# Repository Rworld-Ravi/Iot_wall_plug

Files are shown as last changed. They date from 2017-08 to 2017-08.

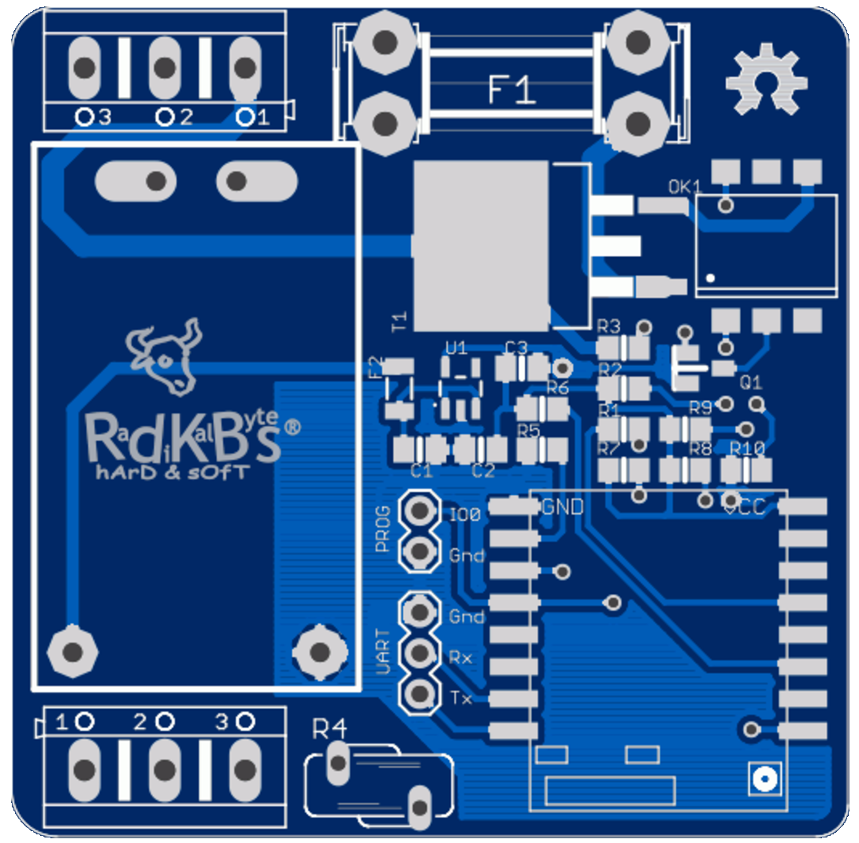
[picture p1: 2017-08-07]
Art/top.png

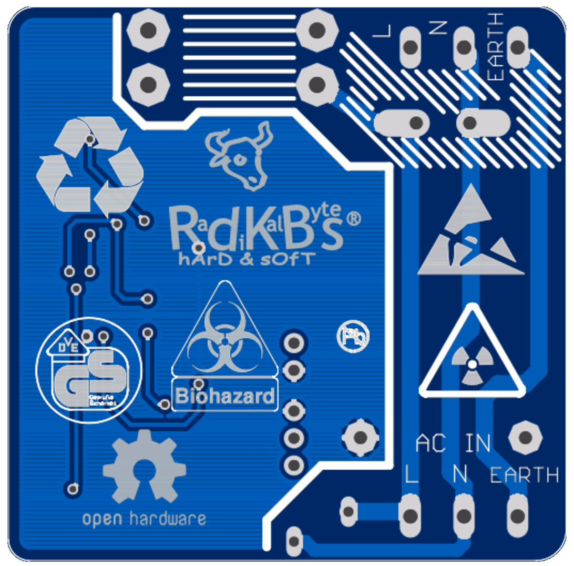
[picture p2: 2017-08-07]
Art/bottom.png

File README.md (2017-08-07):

# IoT wall plug standard

This is a circuit to control any 220v AC device under 4A plugged it.  

## Getting Started with another firmware  

To program the ESP8266 ESP-07 you need an USB <--> serial converter at 3,3v (5v will damage the ESP-07 IOs).  
You can use Arduino IDE to update own sketches.  
Or you can install another firmware in ESP-07 as Lua, uPython, ESPeasy...  
To install another firmware:
* Disconnect device from power  
* Shortcut jumper (IO0 and GND)  
* Connect your favorite USB-serial converter at RX,TX,GND pins  
* Apply power to device (Be careful with 220v AC)
* Upload your firmware with esptool.exe (windows) or another tool for OSX, Linux...  
* Disconnect the jumper (IO0 and GND)
* And restart device

## Built With

[EagleCAD](https://www.autodesk.com/products/eagle/overview)

## Authors

* **RadikalBytes** - *Alfredo Prado* - [@radikalbytes](https://twitter.com/radikalbytes)

## License
<br />This work is licensed under a <a rel="license" href="http://creativecommons.org/licenses/by-sa/3.0/">Creative Commons Attribution-ShareAlike 3.0 Unported License</a>.

## Acknowledgments

* To my brain for support me every hour ;)

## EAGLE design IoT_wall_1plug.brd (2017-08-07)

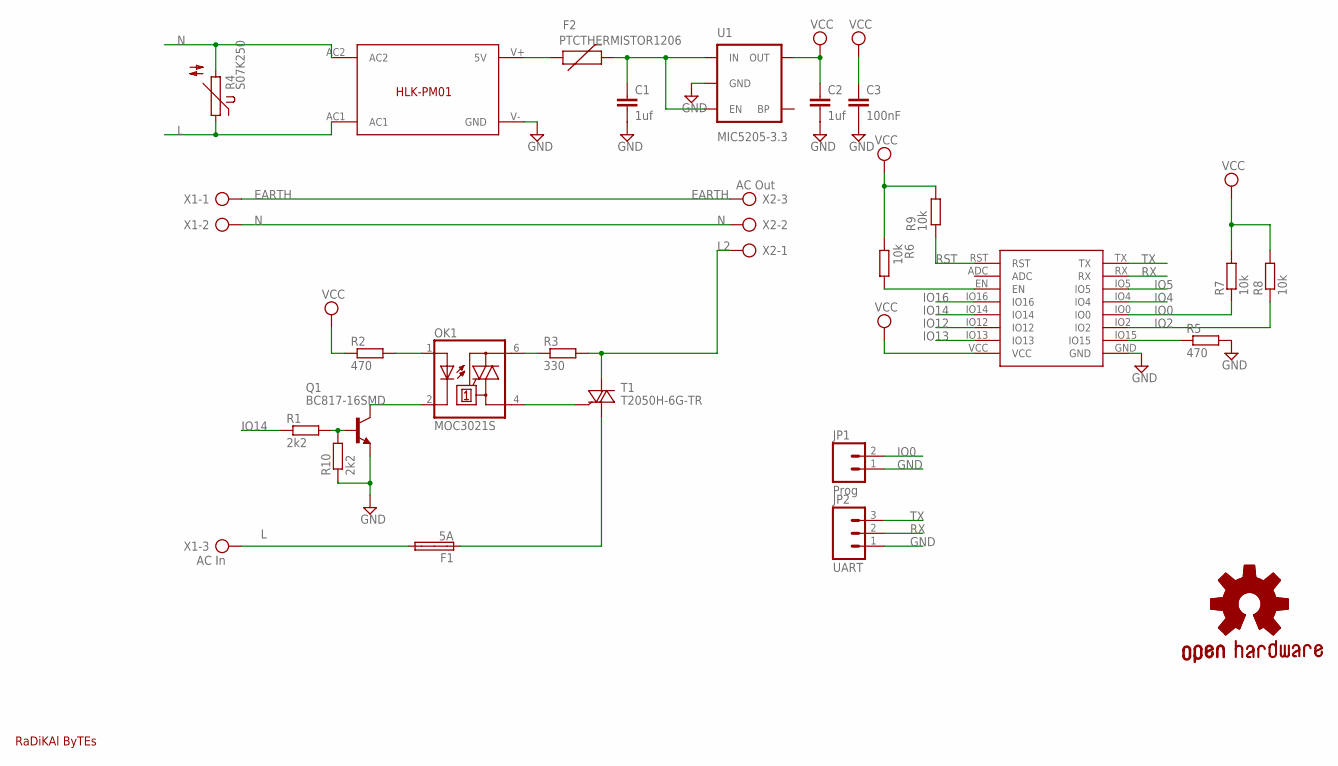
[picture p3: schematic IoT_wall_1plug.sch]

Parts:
C1, C2: 1uf; RCL_C0805K
C3: 100nF; RCL_C0805K
F1: 5A; SHK20Q
F2: PTCTHERMISTOR1206; SPARKFUN-POWERIC_PTC-1206
GOLD_ORB_SM1: OSHWLOGO_GOLD_ORB_MED; OSHW1
JP1: Prog; SPARKFUN-CONNECTORS_1X02
JP2: UART; SPARKFUN-CONNECTORS_1X03
OK1: MOC3021S; DIL6-SMD
Q1: BC817-16SMD; SOT23-BEC
R1, R10: 2k2; R0805
R2, R5: 470; R0805
R3: 330; R0805
R4: S07K250
R6, R7, R8, R9: 10k; R0805
T1: T2050H-6G-TR; D2PAK-3
U1: MIC5205-3.3; SPARKFUN-POWERIC_SOT23-5
U$1: HLK-PM01
U$2: DAVLIB_ESP8266
U$4: MI_LOGO1.5MM; MI_LOGO_PEQUEÑO
X1: AC In; AK500/3
X2: AC Out; AK500/3

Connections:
EARTH: X1.1, X2.3
GND: C1.2, C2.2, C3.2, JP1.1, JP2.1, Q1.E, R5.2, R10.1, U1.2 (GND), U$1.V- (GND), U$2.GND
IO0: JP1.2, R7.1, U$2.IO0
IO2: R8.1, U$2.IO2
IO4: U$2.IO4
IO5: U$2.IO5
IO12: U$2.IO12
IO13: U$2.IO13
IO14: R1.1, U$2.IO14
IO16: U$2.IO16
L: F1.2A, R4.1, U$1.AC1, X1.3
L2: R3.2, T1.4 (A2), X2.1
N: R4.2, U$1.AC2, X1.2, X2.2
unnamed: Q1.B, R1.2, R10.2
unnamed: OK1.1 (A), R2.2
unnamed: OK1.6 (A2), R3.1
unnamed: OK1.2 (C), Q1.C
unnamed: F1.1A, T1.1 (A1)
unnamed: F2.1, U$1.V+ (5V)
unnamed: OK1.4 (A1), T1.3 (G)
unnamed: C1.1, F2.2, U1.1 (IN), U1.3 (EN)
unnamed: R6.2, U$2.EN
unnamed: R5.1, U$2.IO15
RST: R9.1, U$2.RST
RX: JP2.2, U$2.RX
TX: JP2.3, U$2.TX
VCC: C2.1, C3.1, R2.1, R6.1, R7.2, R8.2, R9.2, U1.5 (OUT), U$2.VCC

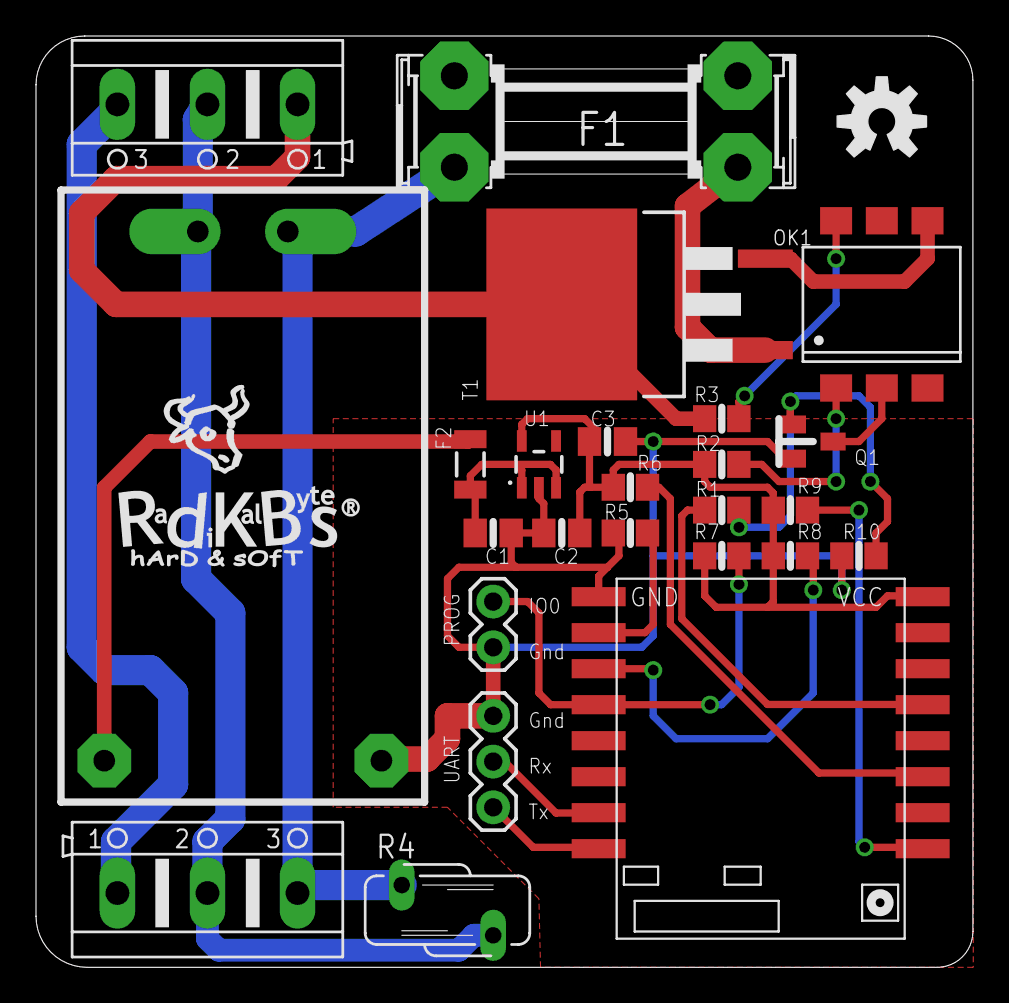
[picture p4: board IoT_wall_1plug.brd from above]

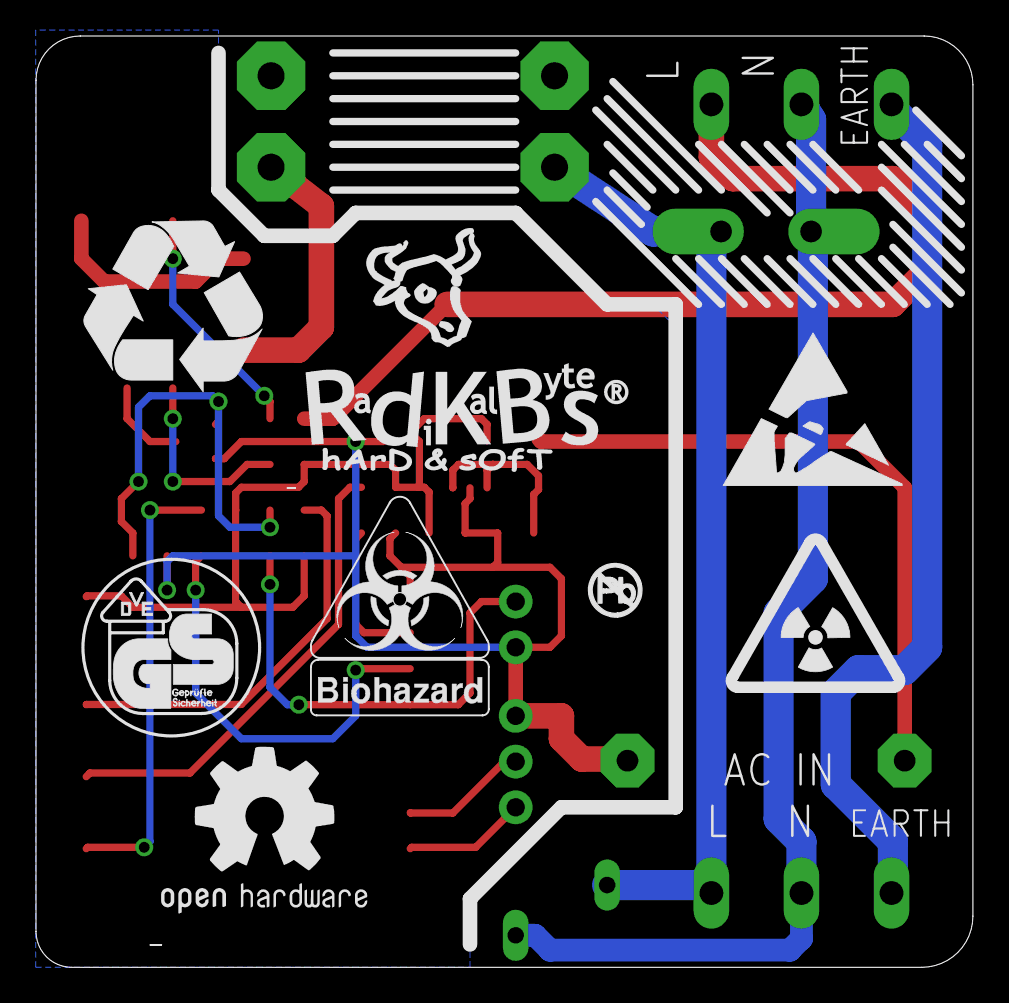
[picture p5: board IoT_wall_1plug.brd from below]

Board: 2 copper layers, 52.0 x 51.7 mm, 35 parts (8 on the bottom side), 22 nets.

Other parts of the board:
U$3: OSHW-LOGO-M
U$5: VDE-GS_10.00
U$6: RECYCLING_10.00
U$7: RADIOACTIVE_10.00
U$8: ESD_10.00
U$9: BIOHAZARD_10.00
U$10: NO_PB_LOGO_0.120
U$12: MI_LOGO_2MM

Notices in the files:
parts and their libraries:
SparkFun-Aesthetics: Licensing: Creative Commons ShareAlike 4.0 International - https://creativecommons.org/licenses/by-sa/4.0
